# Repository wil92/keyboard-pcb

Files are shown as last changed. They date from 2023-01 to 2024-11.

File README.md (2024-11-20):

# keyboard-pcb

A compendium of project about DIY keyboards base on STM32 chips.

> The gerber files are provided and you can use it to replicate the keyboard.

> Also the 3D model for the keyboard is provided in the repository.

## Keyboard Alphanum

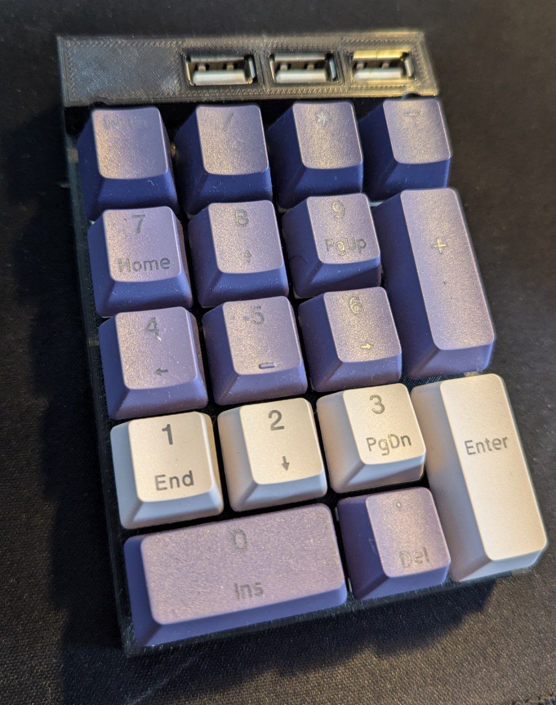
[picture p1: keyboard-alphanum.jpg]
keyboard alphanum example


This is the first keyboard I made. I decided to get an easy option where I can start my incursion on this work of keyboards.
This keyboard could be used as a USB Hub and is a fun project to be made.

## Keyboard Personal

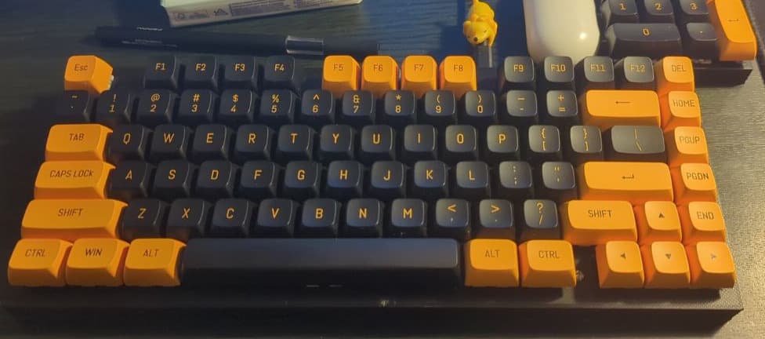
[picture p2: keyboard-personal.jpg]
personal keyboard example


This is a version of 75% keyboard (with some variations).

## Keyboard Split

tbd

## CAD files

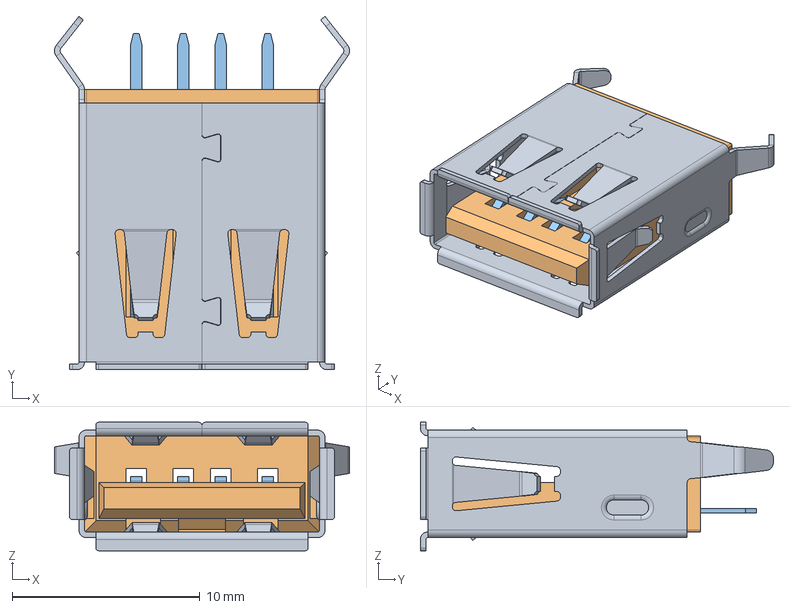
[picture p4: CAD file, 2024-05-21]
common/usb-a-socket.stp
15.7 x 18.8 x 6.84 mm

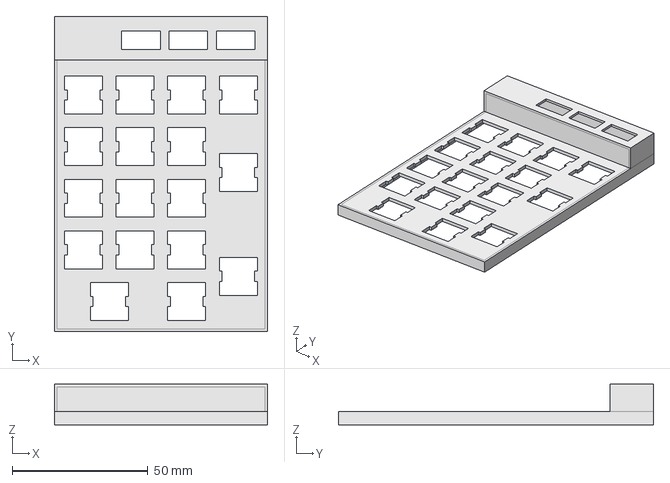
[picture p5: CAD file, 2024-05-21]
keyboard-alphanum/keyboard-case-top.step
78.5 x 116.1 x 15.0 mm

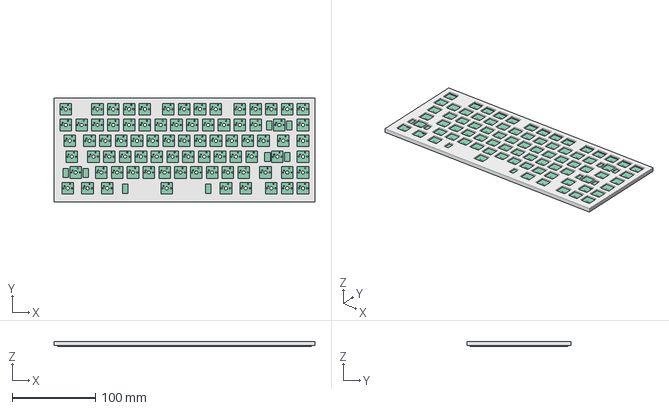
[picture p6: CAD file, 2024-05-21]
keyboard-personal/keyboard-box/keyboard-box.FCStd
314.4 x 125.5 x 6.60 mm
top
Pcb_a2f006

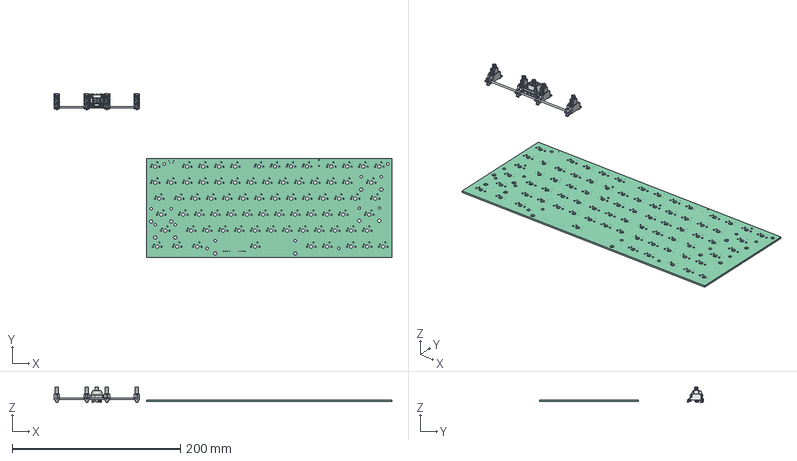
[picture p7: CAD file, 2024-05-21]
keyboard-personal/keyboard_union.FCStd
402.4 x 194.8 x 18.6 mm
SW_Cherry_MX_PCB_cp
SW_Cherry_MX_PCB_cp001
SW_Cherry_MX_PCB_cp002
SW_Cherry_MX_PCB_cp003
SW_Cherry_MX_PCB_cp004
SW_Cherry_MX_PCB_cp005
SW_Cherry_MX_PCB_cp006
Stabilizer_Cherry_MX_2u_cp
Stabilizer_Cherry_MX_2u_cp001
Stabilizer_Cherry_MX_2u_cp002
Stabilizer_Cherry_MX_2u_cp003
Stabilizer_Cherry_MX_2u_cp004
Stabilizer_Cherry_MX_6u_cp
Stabilizer_Cherry_MX_6u_cp001
Stabilizer_Cherry_MX_6u_cp002
Stabilizer_Cherry_MX_6u_cp003
Stabilizer_Cherry_MX_6u_cp004
Pcb_a2f5

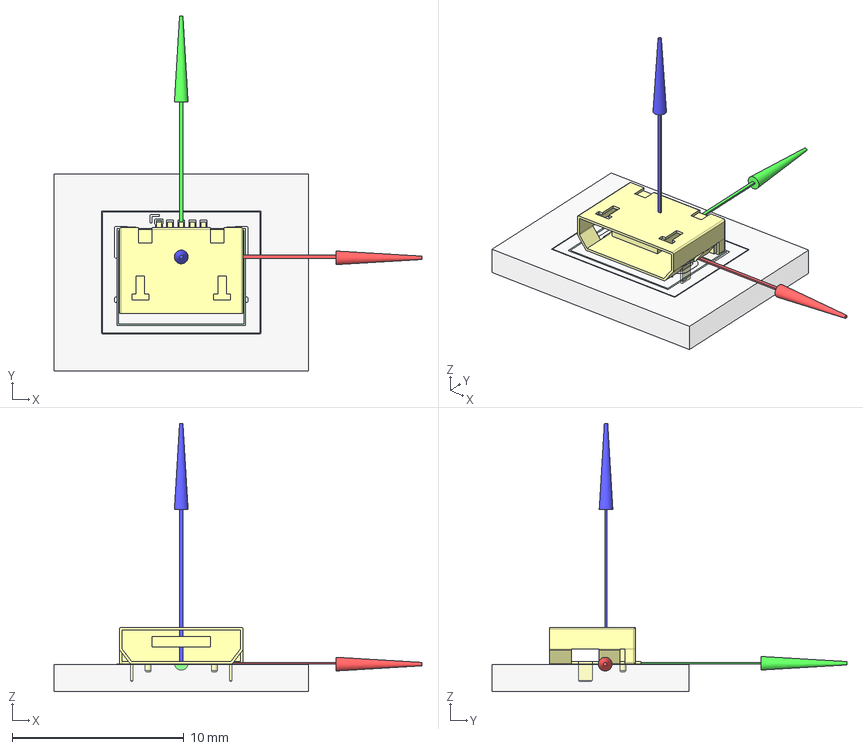
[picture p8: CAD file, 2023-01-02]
usb-3dmodel/usb-245.FCStd
21.4 x 20.6 x 15.6 mm
FCrtYd
FFab
FrontSilk
TopPads
BotPads
PTHs
Pcb
Z
Y
X

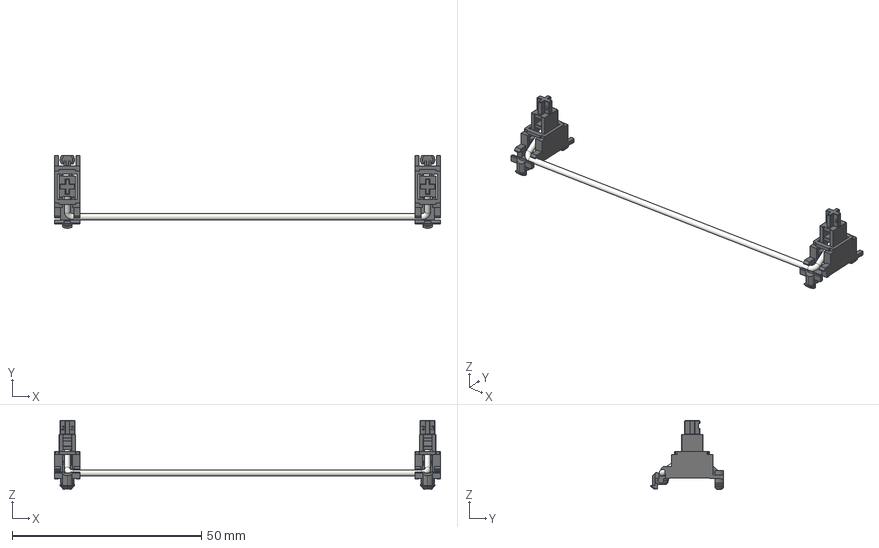
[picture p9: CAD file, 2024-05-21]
common/Stabilizer_Cherry_MX_6.00u.stp
102.1 x 19.2 x 18.3 mm

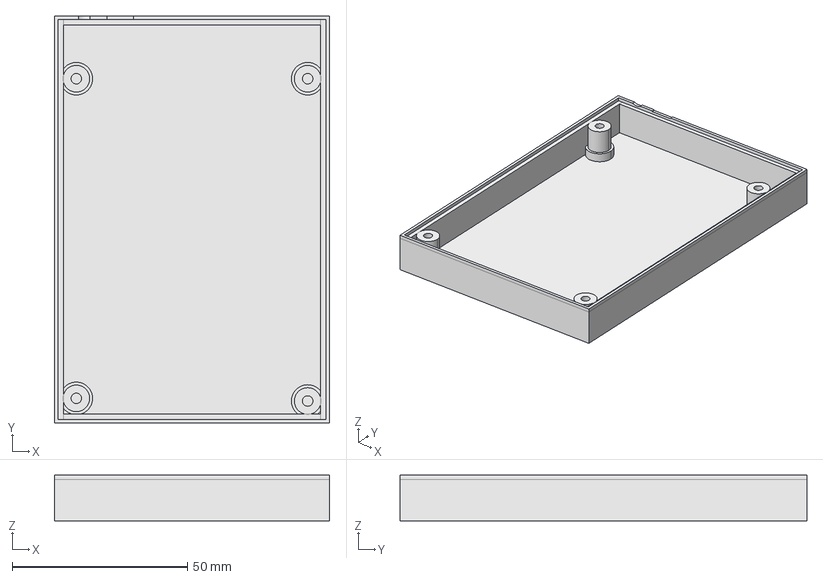
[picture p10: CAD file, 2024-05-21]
keyboard-alphanum/keyboard-case-bottom.step
78.5 x 116.1 x 13.0 mm

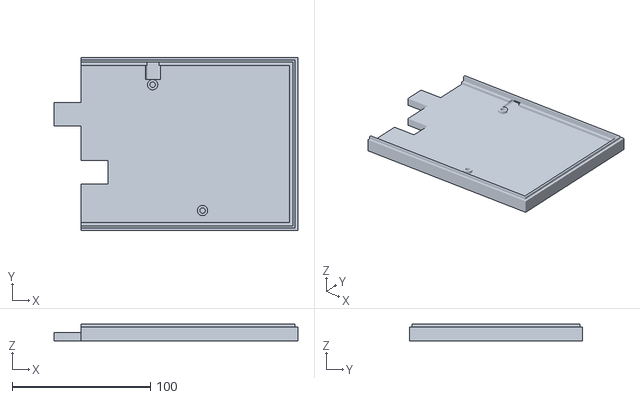
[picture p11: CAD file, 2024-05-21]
keyboard-personal/keyboard-box/slice2-bottom-keyboard-box.stl
176.7 x 125.5 x 12.0

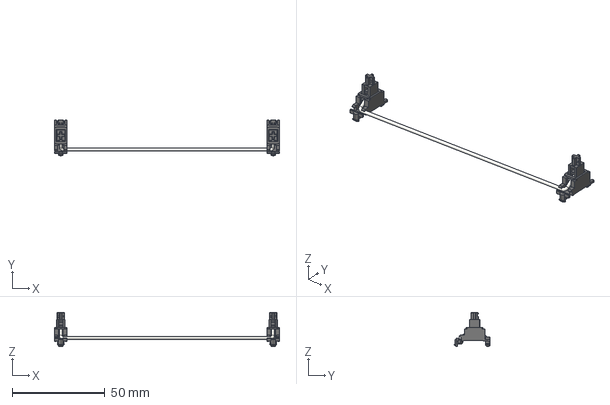
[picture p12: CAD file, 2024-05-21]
common/Stabilizer_Cherry_MX_7.00u.stp
121.1 x 19.2 x 18.3 mm

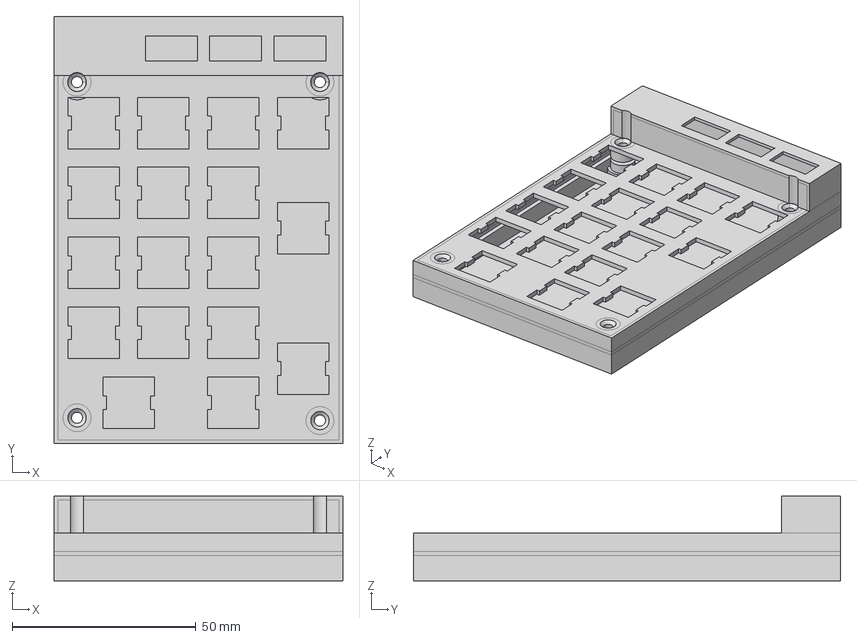
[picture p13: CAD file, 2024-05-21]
keyboard-alphanum/keyboard-case.FCStd
78.5 x 116.1 x 23.0 mm

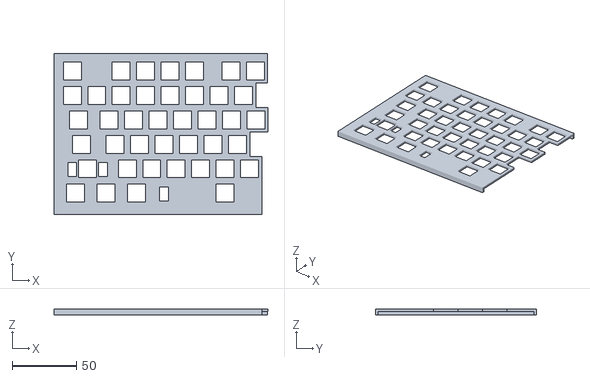
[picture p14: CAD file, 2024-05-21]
keyboard-personal/keyboard-box/keyboard-box-slice-top1.stl
166.6 x 125.5 x 5.00

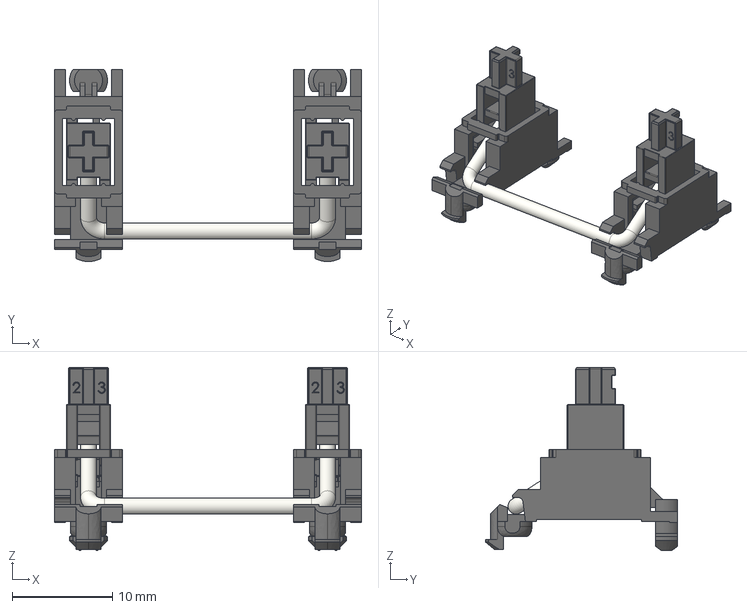
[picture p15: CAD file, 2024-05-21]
common/Stabilizer_Cherry_MX_2.00u.stp
30.7 x 19.2 x 18.3 mm

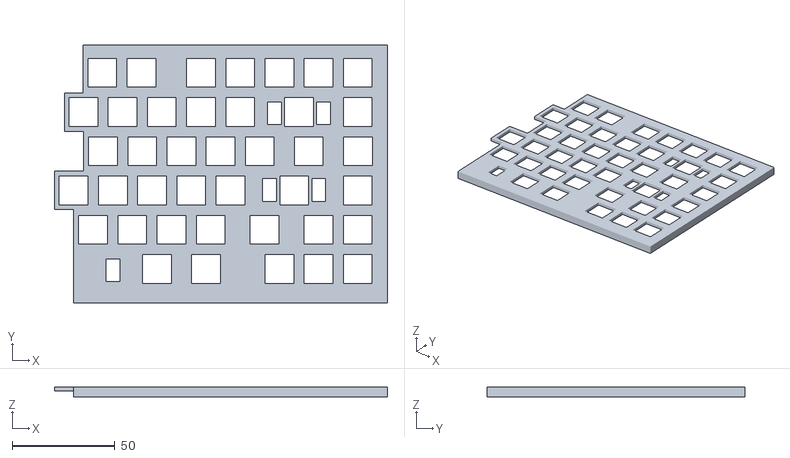
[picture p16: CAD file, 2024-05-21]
keyboard-personal/keyboard-box/keyboard-box-slice-top2.stl
161.8 x 125.5 x 5.00

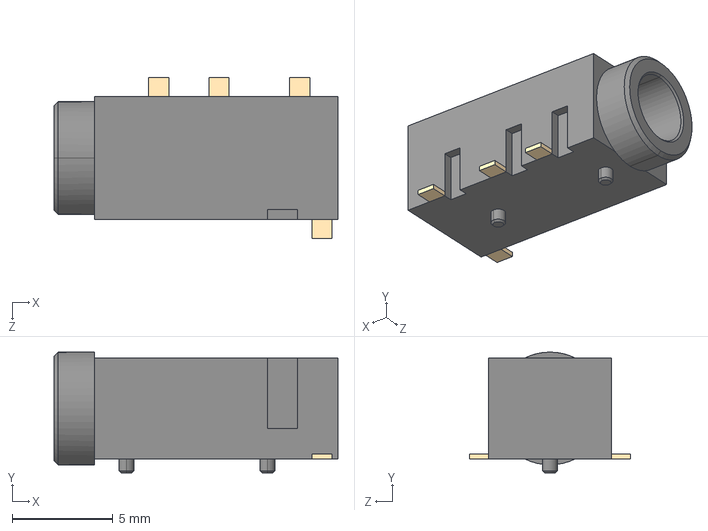
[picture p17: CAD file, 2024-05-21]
common/PJ-320D-A.STEP
14.1 x 6.00 x 8.00 mm

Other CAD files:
keyboard-personal/keyboard-box/slice1-top-keyboard-box.stl
common/usb-245.step
keyboard-personal/keyboard-box/slice2-top-keyboard-box.stl
common/SW_Cherry_MX_PCB.stp
keyboard-alphanum/keyboard-case-bottom.stl
keyboard-alphanum/keyboard-case-top.stl
keyboard-personal/keyboard-box/slice-keyboard.stl
keyboard-personal/keyboard-box/slice1-bottom-keyboard-box.stl

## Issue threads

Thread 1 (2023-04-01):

Todo in the alphanumeric keyboard

wil92, 2023-04-01:
# Todo list

- [ ] Add notation on the programmable pins.
- [ ] Fix the issue with the USB connector's voltage.
- [ ] Fix the issue with pins in the 32768 crystal.
- [ ] Add test points for the important pins
- [ ] Make an external circuit to enable the stm32 to programable mode (take this circuit out of the design).
- [ ] Remove LEDs and related to them resistors.

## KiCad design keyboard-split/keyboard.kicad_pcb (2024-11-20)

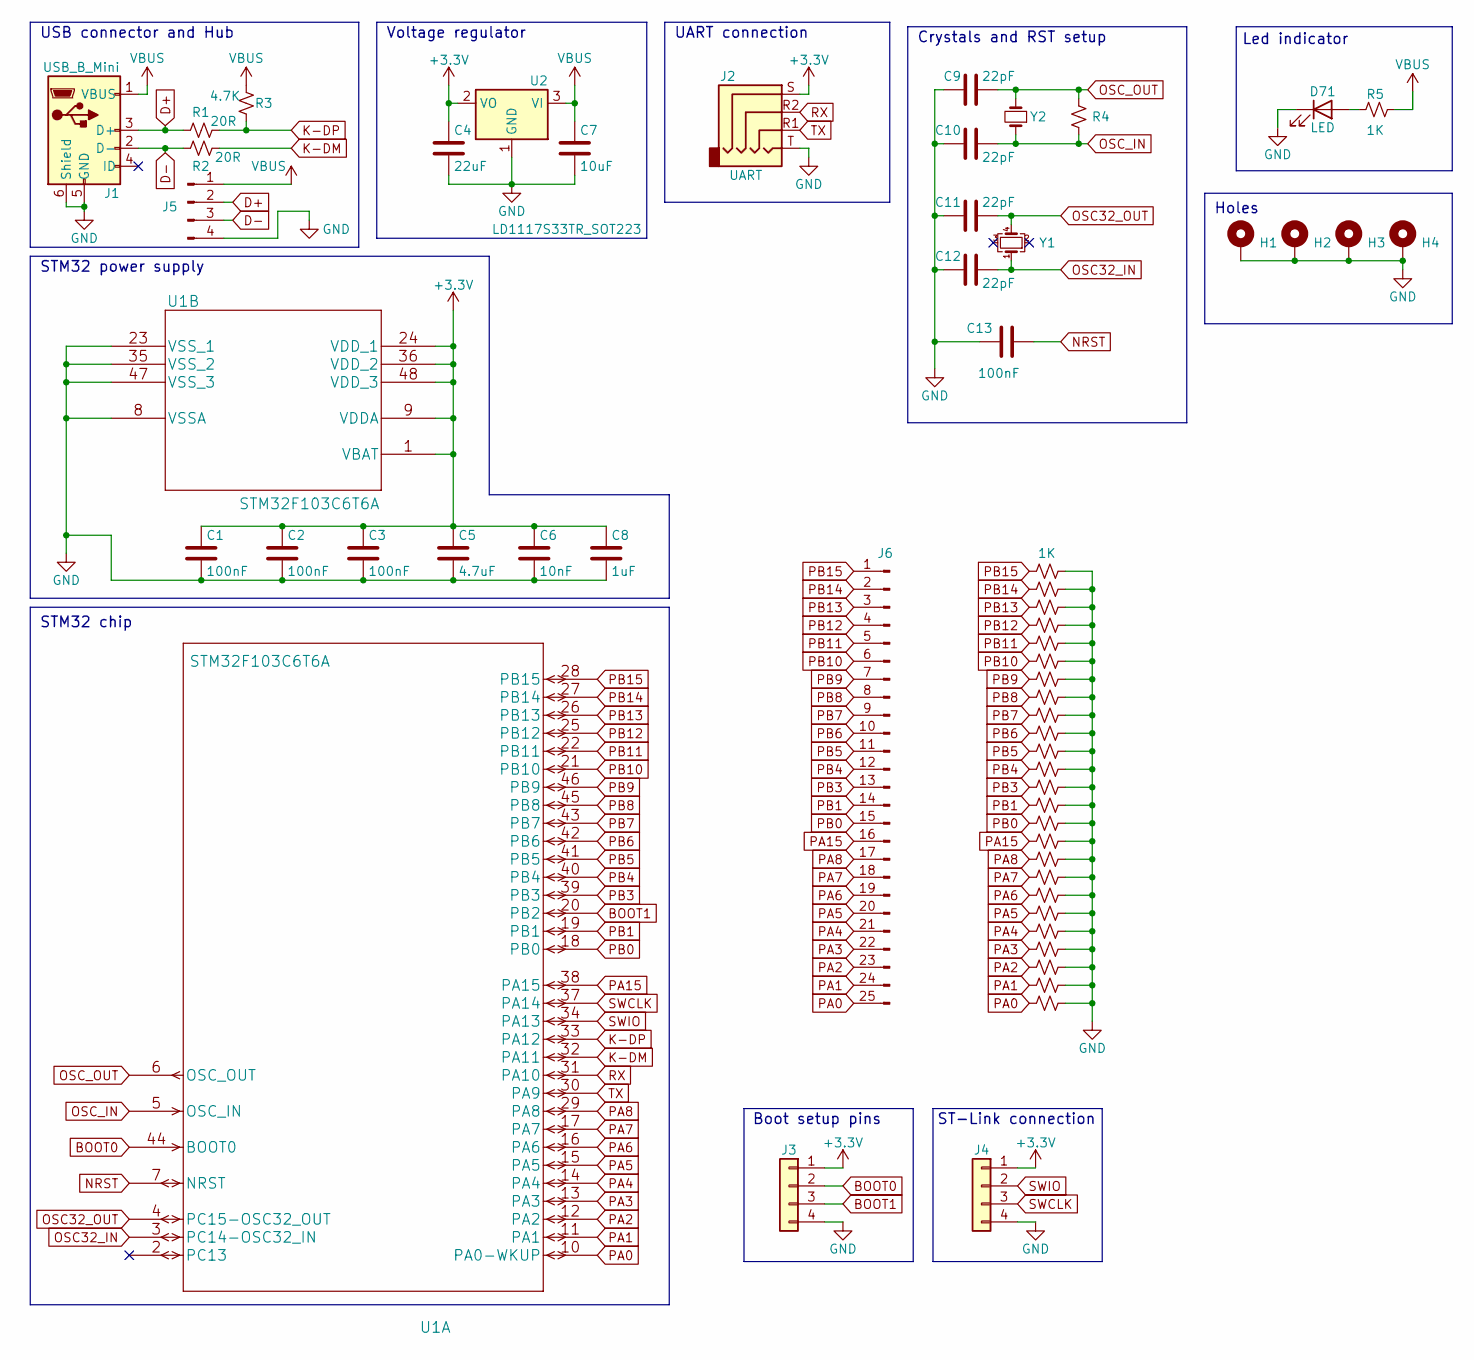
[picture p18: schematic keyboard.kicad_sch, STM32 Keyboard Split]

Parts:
C1, C2, C3, C13: 100nF; C_0805_2012Metric
C4: 22uF; C_1206_3216Metric
C5: 4.7uF; C_0805_2012Metric
C6: 10nF; C_0805_2012Metric
C7: 10uF; C_1206_3216Metric
C8: 1uF; C_0805_2012Metric
C9, C10, C11, C12: 22pF; C_0805_2012Metric
D71: LED; LED_0805_2012Metric
H1, H2, H3, H4: MountingHole; MountingHole_3.2mm_M3_DIN965_Pad
J1: USB_B_Mini; USB_Micro-B_A01SB141B1-245
J2: UART; PJ320D
J3, J4: Conn_01x04; PinHeader_1x04_P2.54mm_Vertical
J5: Conn_01x04_Pin; PinSocket_1x04_P1.27mm_Vertical
J6: Conn_01x25_Pin; PinHeader_1x25_P2.54mm_Vertical
R1, R2: 20R; R_0805_2012Metric
R3: 4.7K; R_0805_2012Metric
R4: R_Small_US; R_0805_2012Metric
R5, R6, R7, R8, R9, R10, R11, R12, R13, R14, R15, R16, R17, R18, R19, R20, R21, R22, R23, R24, R25, R26, R27, R28, R29, R30: 1K; R_0805_2012Metric
U1: STM32F103C6T6A; LQFP-48_7x7mm_P0.5mm
U2: LD1117S33TR_SOT223; SOT-223-3_TabPin2
Y1: Crystal_GND23_Small; Crystal_SMD_SeikoEpson_MC306-4Pin_8.0x3.2mm
Y2: Crystal_Small; Crystal_SMD_Abracon_ABM3-2Pin_5.0x3.2mm

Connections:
+3.3V: C1.1, C2.1, C3.1, C4.1, C5.1, C6.1, C8.1, J2.S, J3.1, J4.1, U1.1 (VBAT), U1.9 (VDDA), U1.24 (VDD_1), U1.36 (VDD_2), U1.48 (VDD_3), U2.2 (VO); also elsewhere on the board
BOOT0: J3.2, U1.44 (BOOT0)
BOOT1: J3.3, U1.20 (PB2)
D+: J1.3 (D+), J5.2, R1.1
D-: J1.2 (D-), J5.3, R2.1
GND: C1.2, C2.2, C3.2, C4.2, C5.2, C6.2, C7.2, C8.2, C9.1, C10.1, C11.1, C12.1, C13.1, D71.1 (K), H1.1, H2.1, H3.1, H4.1, J1.5 (GND), J1.6 (Shield), J2.T, J3.4, J4.4, J5.4, R6.2, R7.2, R8.2, R9.2, R10.2, R11.2, R12.2, R13.2, R14.2, R15.2, R16.2, R17.2, R18.2, R19.2, R20.2, R21.2, R22.2, R23.2, R24.2, R25.2, R26.2, R27.2, R28.2, R29.2, R30.2, U1.8 (VSSA), U1.23 (VSS_1), U1.35 (VSS_2), U1.47 (VSS_3), U2.1 (GND); also elsewhere on the board
K-DM: R2.2, U1.32 (PA11)
K-DP: R1.2, R3.1, U1.33 (PA12)
NRST: C13.2, U1.7 (NRST)
unnamed: D71.2 (A), R5.1
OSC32_IN: C12.2, U1.3 (PC14-OSC32_IN), Y1.1
OSC32_OUT: C11.2, U1.4 (PC15-OSC32_OUT), Y1.4
OSC_IN: C10.2, R4.1, U1.5 (OSC_IN), Y2.1
OSC_OUT: C9.2, R4.2, U1.6 (OSC_OUT), Y2.2
PA0: J6.25, R30.1, U1.10 (PA0-WKUP)
PA1: J6.24, R29.1, U1.11 (PA1)
PA2: J6.23, R28.1, U1.12 (PA2)
PA3: J6.22, R27.1, U1.13 (PA3)
PA4: J6.21, R26.1, U1.14 (PA4)
PA5: J6.20, R25.1, U1.15 (PA5)
PA6: J6.19, R24.1, U1.16 (PA6)
PA7: J6.18, R23.1, U1.17 (PA7)
PA8: J6.17, R22.1, U1.29 (PA8)
PA15: J6.16, R21.1, U1.38 (PA15)
PB0: J6.15, R20.1, U1.18 (PB0)
PB1: J6.14, R19.1, U1.19 (PB1)
PB3: J6.13, R18.1, U1.39 (PB3)
PB4: J6.12, R12.1, U1.40 (PB4)
PB5: J6.11, R11.1, U1.41 (PB5)
PB6: J6.10, R10.1, U1.42 (PB6)
PB7: J6.9, R9.1, U1.43 (PB7)
PB8: J6.8, R17.1, U1.45 (PB8)
PB9: J6.7, R16.1, U1.46 (PB9)
PB10: J6.6, R15.1, U1.21 (PB10)
PB11: J6.5, R14.1, U1.22 (PB11)
PB12: J6.4, R13.1, U1.25 (PB12)
PB13: J6.3, R8.1, U1.26 (PB13)
PB14: J6.2, R6.1, U1.27 (PB14)
PB15: J6.1, R7.1, U1.28 (PB15)
RX: J2.R2, U1.31 (PA10); also elsewhere on the board
SWCLK: J4.3, U1.37 (PA14)
SWIO: J4.2, U1.34 (PA13)
TX: J2.R1, U1.30 (PA9); also elsewhere on the board
VBUS: C7.1, J1.1 (VBUS), J5.1, R3.2, R5.2, U2.3 (VI)

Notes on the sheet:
STM32 chip
STM32 power supply
ST-Link connection
Holes
Led indicator
Boot setup pins
Crystals and RST setup
Voltage regulator
UART connection
USB connector and Hub

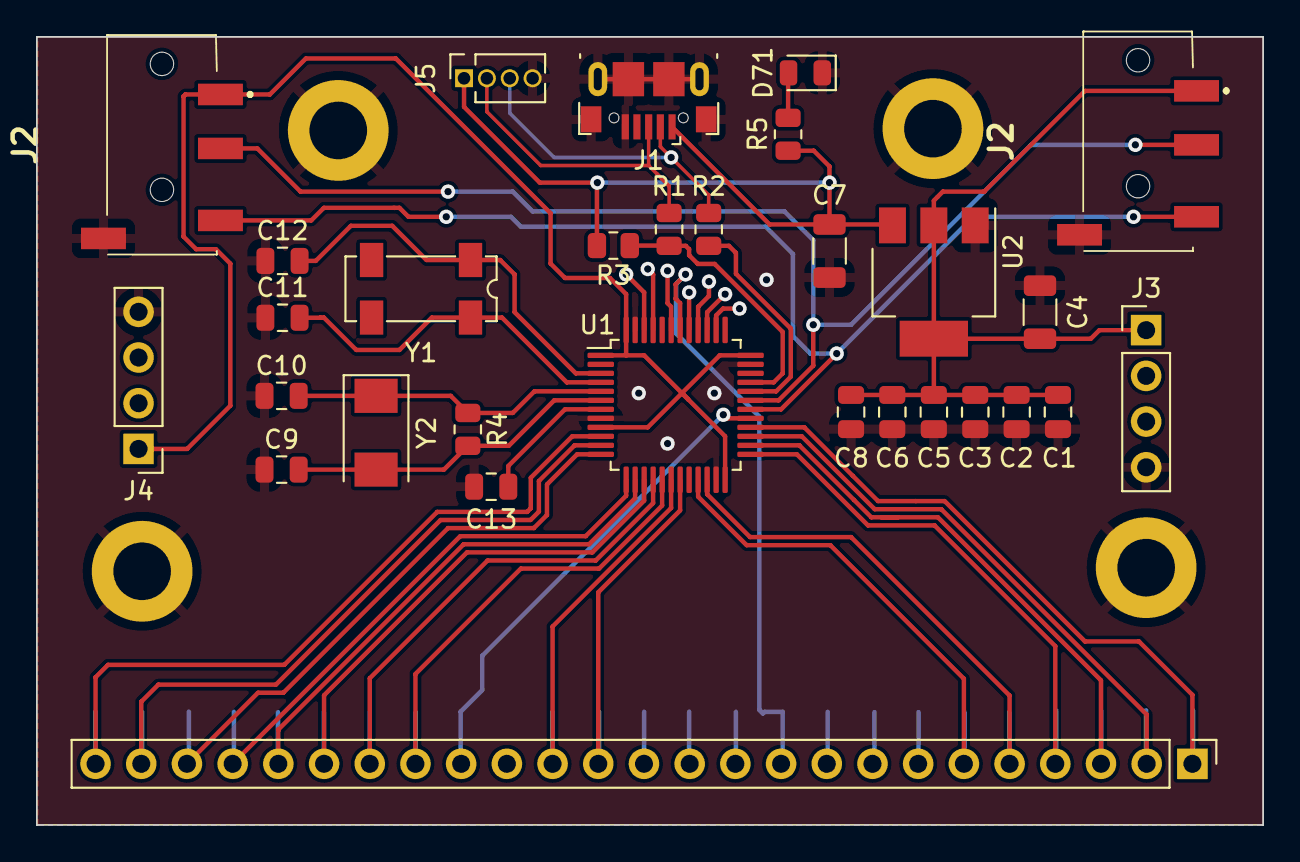
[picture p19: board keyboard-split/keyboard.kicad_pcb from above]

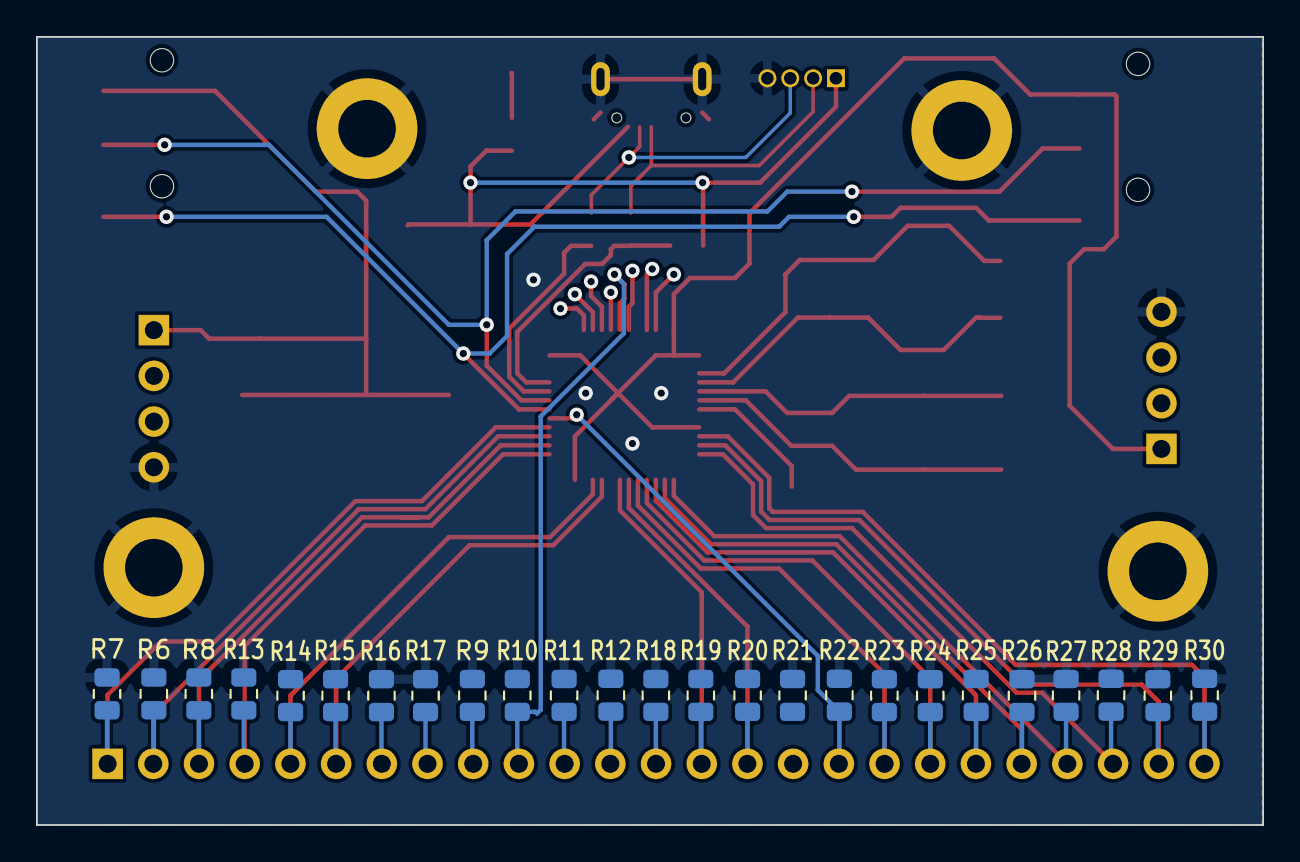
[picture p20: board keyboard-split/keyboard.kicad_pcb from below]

Board: 2 copper layers, 68.1 x 43.8 mm, 59 parts (25 on the bottom side), 44 nets.

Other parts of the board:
J2#2: UART; PJ320D

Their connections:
+3.3V: J2#2.S; also elsewhere on the board
GND: J2#2.T; also elsewhere on the board
RX: J2#2.R2; also elsewhere on the board
TX: J2#2.R1; also elsewhere on the board

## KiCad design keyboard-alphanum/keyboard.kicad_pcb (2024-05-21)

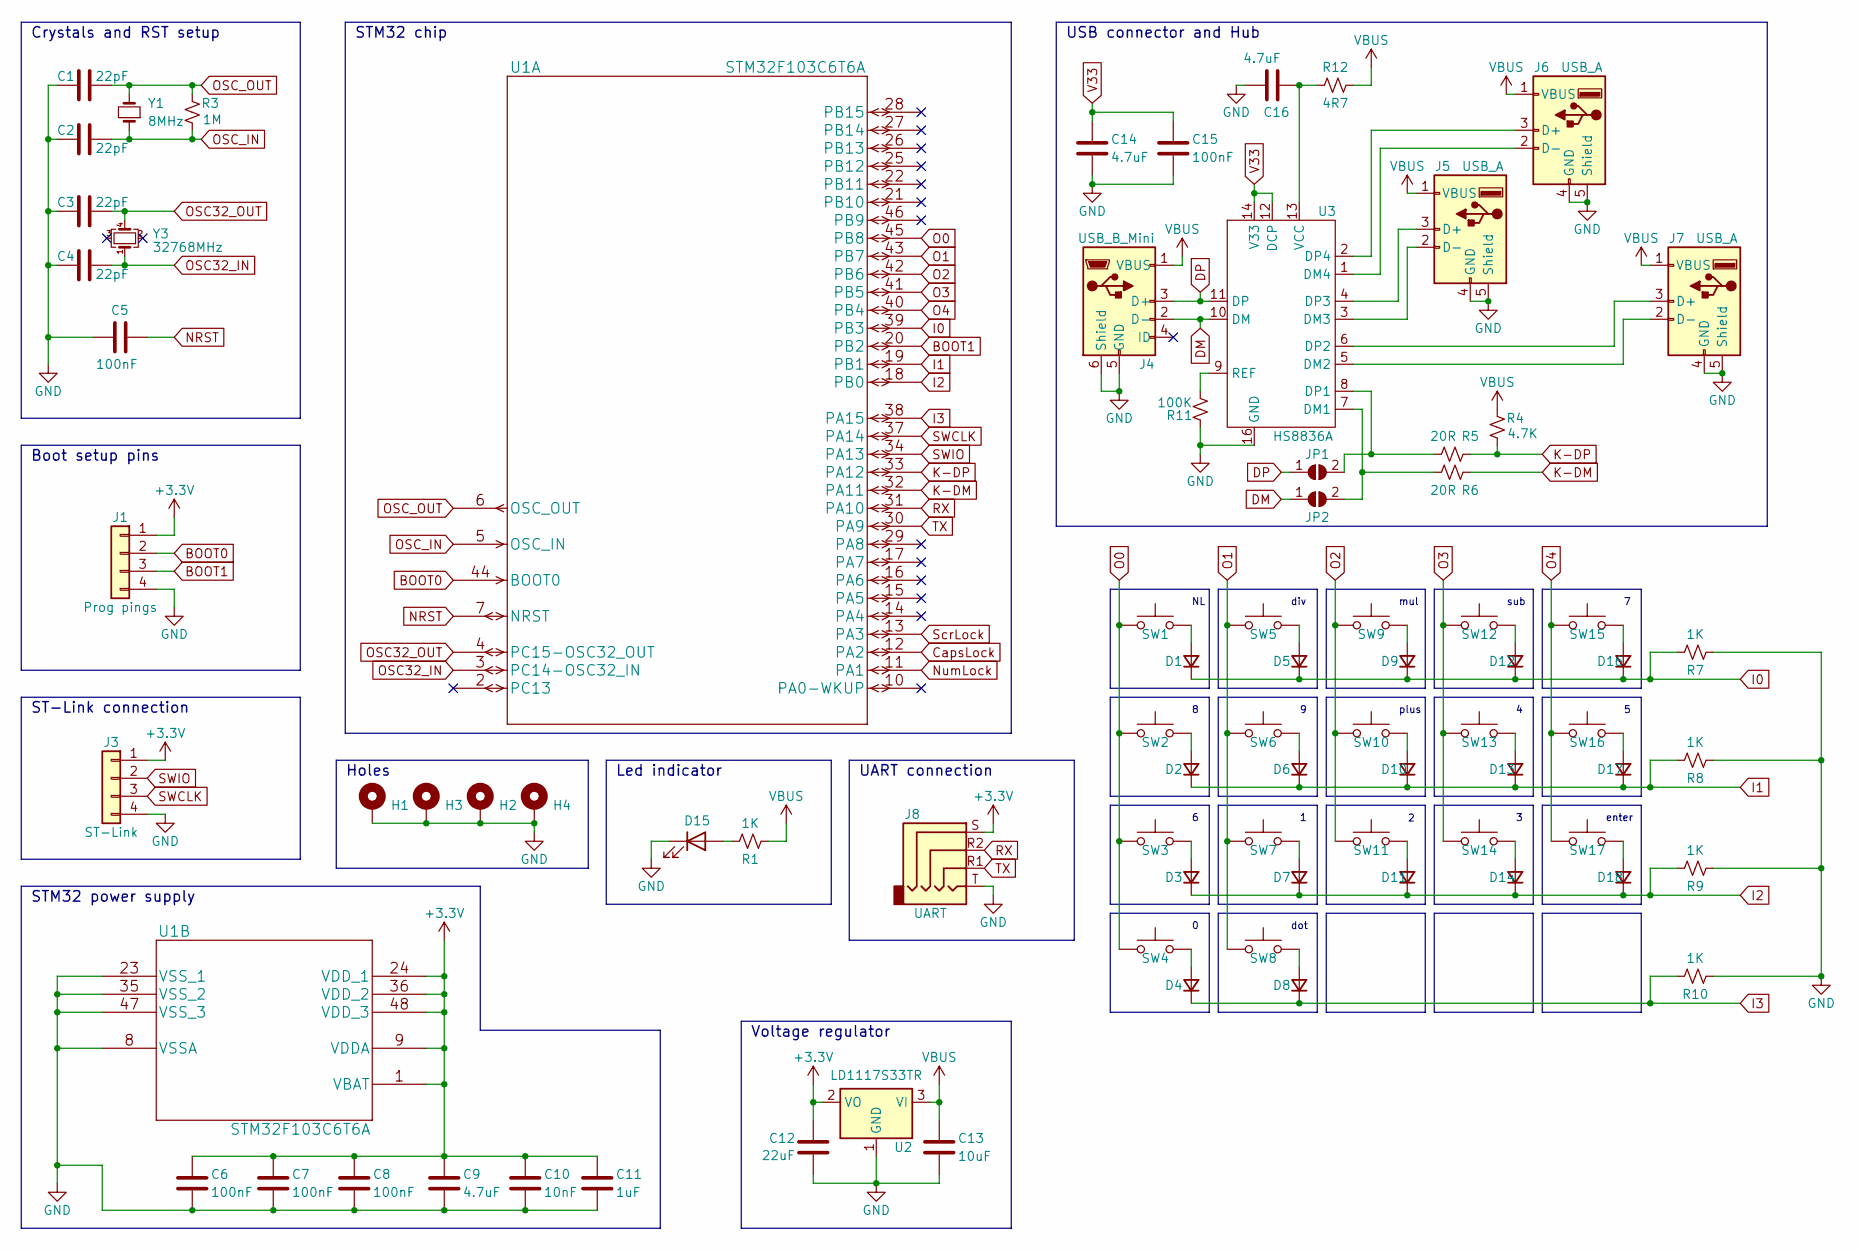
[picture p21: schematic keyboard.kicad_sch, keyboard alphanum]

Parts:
C1, C2, C3, C4: 22pF; C_0805_2012Metric
C5, C6, C7, C8, C15: 100nF; C_0805_2012Metric
C9, C14, C16: 4.7uF; C_0805_2012Metric
C10: 10nF; C_0805_2012Metric
C11: 1uF; C_0805_2012Metric
C12: 22uF; C_1206_3216Metric
C13: 10uF; C_1206_3216Metric
D1, D2, D3, D4, D5, D6, D7, D8, D9, D10, D11, D12, D13, D14, D16, D17, D18: D_Small; D_SOD-323
D15: LED; LED_0805_2012Metric
H1, H2, H3, H4: MountingHole; MountingHole_3.2mm_M3_DIN965_Pad
J1: Prog pings; PinHeader_1x04_P2.54mm_Vertical
J3: ST-Link; PinHeader_1x04_P2.54mm_Vertical
J4: USB_B_Mini; USB_Micro-B_A01SB141B1-245
J5, J6, J7: USB_A; USB_A_Molex_105057_Vertical
J8: UART; PJ320D
JP1, JP2: SolderJumper_2_Open; SolderJumper-2_P1.3mm_Open_RoundedPad1.0x1.5mm
R1, R7, R8, R9, R10: 1K; R_0805_2012Metric
R3: 1M; R_0805_2012Metric
R4: 4.7K; R_0805_2012Metric
R5, R6: 20R; R_0805_2012Metric
R11: 100K; R_0805_2012Metric
R12: 4R7; R_0805_2012Metric
SW1: NL; SW_Cherry_MX_PCB_1.00u
SW2: 8; SW_Cherry_MX_PCB_1.00u
SW3: 6; SW_Cherry_MX_PCB_1.00u
SW4: 0; SW_Cherry_MX_PCB_2.00u
SW5: div; SW_Cherry_MX_PCB_1.00u
SW6: 9; SW_Cherry_MX_PCB_1.00u
SW7: 1; SW_Cherry_MX_PCB_1.00u
SW8: dot; SW_Cherry_MX_PCB_1.00u
SW9: mul; SW_Cherry_MX_PCB_1.00u
SW10: plus; SW_Cherry_MX_PCB_2.00u_90deg
SW11: 2; SW_Cherry_MX_PCB_1.00u
SW12: sub; SW_Cherry_MX_PCB_1.00u
SW13: 4; SW_Cherry_MX_PCB_1.00u
SW14: 3; SW_Cherry_MX_PCB_1.00u
SW15: 7; SW_Cherry_MX_PCB_1.00u
SW16: 5; SW_Cherry_MX_PCB_1.00u
SW17: enter; SW_Cherry_MX_PCB_2.00u_90deg
U1: STM32F103C6T6A; LQFP-48_7x7mm_P0.5mm
U2: LD1117S33TR; SOT-223-3_TabPin2
U3: HS8836A; SOP-16_3.9x9.9mm_P1.27mm
Y1: 8MHz; Crystal_SMD_Abracon_ABM3-2Pin_5.0x3.2mm
Y3: 32768MHz; Crystal_SMD_SeikoEpson_MC306-4Pin_8.0x3.2mm

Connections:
+3.3V: C6.1, C7.1, C8.1, C9.1, C10.1, C11.1, C12.1, J1.1, J3.1, J8.S, U1.1 (VBAT), U1.9 (VDDA), U1.24 (VDD_1), U1.36 (VDD_2), U1.48 (VDD_3), U2.2 (VO)
BOOT0: J1.2, U1.44 (BOOT0)
BOOT1: J1.3, U1.20 (PB2)
CapsLock: U1.12 (PA2)
DM: J4.2 (D-), JP2.1 (A), U3.10 (DM)
DP: J4.3 (D+), JP1.1 (A), U3.11 (DP)
GND: C1.1, C2.1, C3.1, C4.1, C5.1, C6.2, C7.2, C8.2, C9.2, C10.2, C11.2, C12.2, C13.2, C14.2, C15.2, C16.1, D15.1 (K), H1.1, H2.1, H3.1, H4.1, J1.4, J3.4, J4.5 (GND), J4.6 (Shield), J5.4 (GND), J5.5 (Shield), J6.4 (GND), J6.5 (Shield), J7.4 (GND), J7.5 (Shield), J8.T, R7.2, R8.2, R9.2, R10.2, R11.2, U1.8 (VSSA), U1.23 (VSS_1), U1.35 (VSS_2), U1.47 (VSS_3), U2.1 (GND), U3.16 (GND)
I0: D1.1 (K), D5.1 (K), D9.1 (K), D12.1 (K), D16.1 (K), R7.1, U1.39 (PB3)
I1: D2.1 (K), D6.1 (K), D10.1 (K), D13.1 (K), D17.1 (K), R8.1, U1.19 (PB1)
I2: D3.1 (K), D7.1 (K), D11.1 (K), D14.1 (K), D18.1 (K), R9.1, U1.18 (PB0)
I3: D4.1 (K), D8.1 (K), R10.1, U1.38 (PA15)
K-DM: R6.2, U1.32 (PA11)
K-DP: R4.1, R5.2, U1.33 (PA12)
NRST: C5.2, U1.7 (NRST)
unnamed: D1.2 (A), SW1.2
unnamed: D2.2 (A), SW2.2
unnamed: D3.2 (A), SW3.2
unnamed: D4.2 (A), SW4.2
unnamed: D5.2 (A), SW5.2
unnamed: D6.2 (A), SW6.2
unnamed: D7.2 (A), SW7.2
unnamed: D8.2 (A), SW8.2
unnamed: D9.2 (A), SW9.2
unnamed: D10.2 (A), SW10.2
unnamed: D11.2 (A), SW11.2
unnamed: D12.2 (A), SW12.2
unnamed: D13.2 (A), SW13.2
unnamed: D14.2 (A), SW14.2
unnamed: D15.2 (A), R1.1
unnamed: D16.2 (A), SW15.2
unnamed: D17.2 (A), SW16.2
unnamed: D18.2 (A), SW17.2
unnamed: J5.3 (D+), U3.4 (DP3)
unnamed: J5.2 (D-), U3.3 (DM3)
unnamed: J6.3 (D+), U3.2 (DP4)
unnamed: J6.2 (D-), U3.1 (DM4)
unnamed: J7.3 (D+), U3.6 (DP2)
unnamed: J7.2 (D-), U3.5 (DM2)
unnamed: JP1.2 (B), R5.1, U3.8 (DP1)
unnamed: JP2.2 (B), R6.1, U3.7 (DM1)
unnamed: R11.1, U3.9 (REF)
unnamed: C16.2, R12.1, U3.13 (VCC)
NumLock: U1.11 (PA1)
O0: SW1.1, SW2.1, SW3.1, SW4.1, U1.45 (PB8)
O1: SW5.1, SW6.1, SW7.1, SW8.1, U1.43 (PB7)
O2: SW9.1, SW10.1, SW11.1, U1.42 (PB6)
O3: SW12.1, SW13.1, SW14.1, U1.41 (PB5)
O4: SW15.1, SW16.1, SW17.1, U1.40 (PB4)
OSC32_IN: C4.2, U1.3 (PC14-OSC32_IN), Y3.1
OSC32_OUT: C3.2, U1.4 (PC15-OSC32_OUT), Y3.4
OSC_IN: C2.2, R3.1, U1.5 (OSC_IN), Y1.1
OSC_OUT: C1.2, R3.2, U1.6 (OSC_OUT), Y1.2
RX: J8.R2, U1.31 (PA10)
SWCLK: J3.3, U1.37 (PA14)
SWIO: J3.2, U1.34 (PA13)
ScrLock: U1.13 (PA3)
TX: J8.R1, U1.30 (PA9)
V33: C14.1, C15.1, U3.12 (DCP), U3.14 (V33)
VBUS: C13.1, J4.1 (VBUS), J5.1 (VBUS), J6.1 (VBUS), J7.1 (VBUS), R1.2, R4.2, R12.2, U2.3 (VI)

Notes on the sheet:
Voltage regulator
STM32 chip
plus
div
Led indicator
USB connector and Hub
sub
Crystals and RST setup
STM32 power supply
Holes
UART connection
enter
Boot setup pins
ST-Link connection
mul
dot

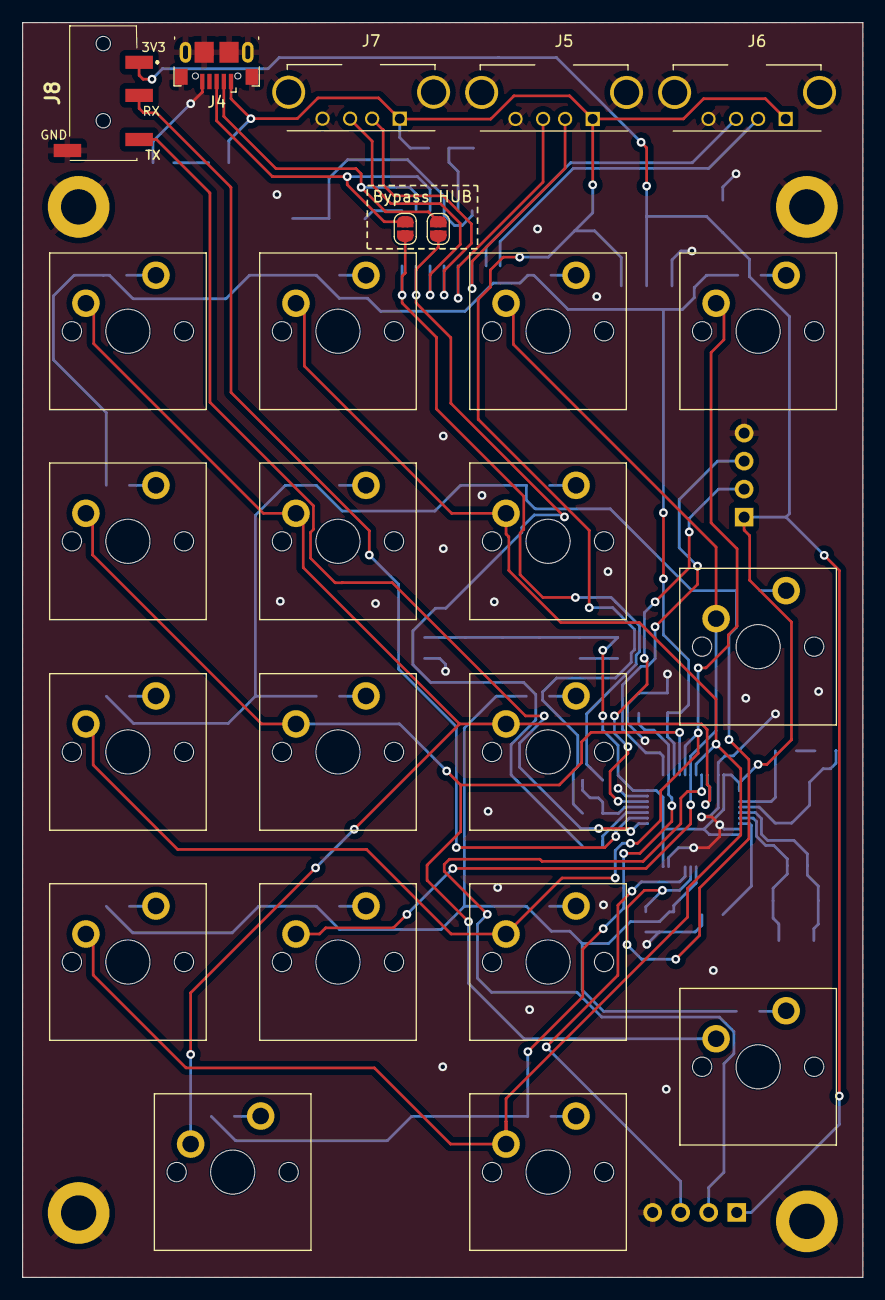
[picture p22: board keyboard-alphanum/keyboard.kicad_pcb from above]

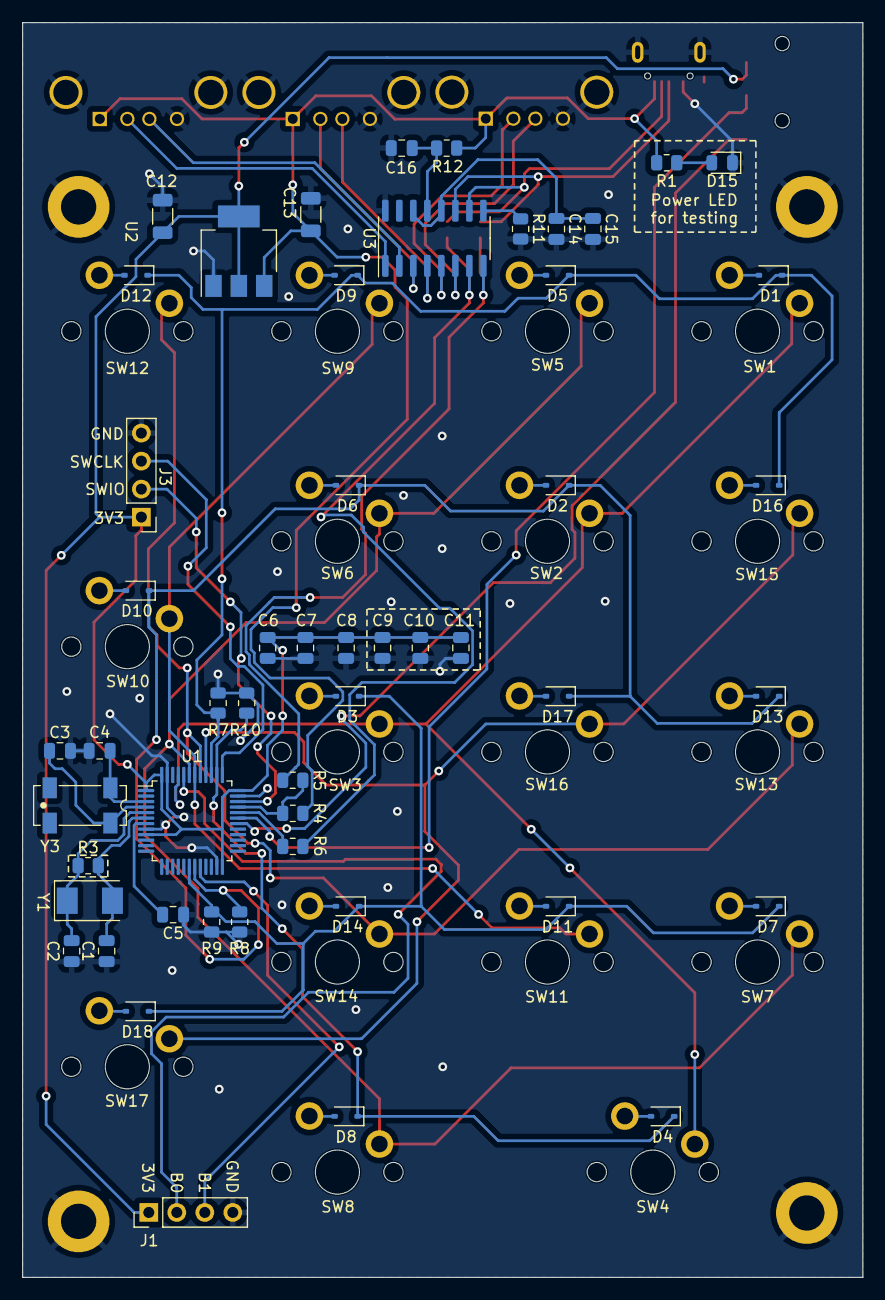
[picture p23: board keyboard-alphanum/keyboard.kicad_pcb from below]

Board: 2 copper layers, 76.2 x 113.8 mm, 80 parts (52 on the bottom side), 56 nets.

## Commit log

2022-07-31 Update personal and organize data
    [SW_Cherry_MX_PCB.stp, keyboard.kicad_pcb, keyboard.kicad_sch]
2022-07-31 Keyboard alphanum v1.0
    [keyboard.kicad_sch]
2023-01-02 Update keyboar pcb design
    [Fusion.step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]
2023-07-07 Fix issues and update alphanum keyboard
    [keyboard-B_Cu.gbl, keyboard-B_Mask.gbs, keyboard-B_Paste.gbp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]
2024-05-21 Update latest version of keyboard-personal
    [PJ-320D-A.STEP, Stabilizer_Cherry_MX_2.00u.stp, Stabilizer_Cherry_MX_6.00u.stp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]
2024-11-20 First version of split keyboard
    [keyboard.kicad_pcb, keyboard.kicad_sch]
